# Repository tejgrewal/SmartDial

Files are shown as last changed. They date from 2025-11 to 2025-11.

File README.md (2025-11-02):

# SmartDial

This project is proff of concept, that used a Round Display, Dial, Haptics with power of ESP32-S3 as main controller.

Features
- Menu-driven launcher with games (Pong, Snake, Maze), Torch app and BLE-based Launcher.
- Uses Seeed_GFX / TFT_eSPI for display rendering.
- Haptics and BNO sensor support.
- Modular app interface via the Modulino knob.

CAD Folder- All the model files are in CAD folder

BOM Folder - Bill of material of the items required to make one SmartDial

Assembly & Fabrication Folder - Contain notes on important items. Please read carefully before commiting or start of project. 

Quick links to main code & modules
- [`src/main.cpp`](src/main.cpp)
- UI / menu: [`Menu::init`](lib/Menu/Menu.h)
- Torch app: [`Torch::initOnce`](lib/Apps/Torch.h)
- Pong: [`Pong::init`](lib/Games/Pong.h)
- Snake: [`Snake::init`](lib/Games/Snake.h)
- Maze: [`Maze::init`](lib/Games/Maze.h)
- Launcher (BLE GATT): [`Launcher::init`](lib/Launcher/Launcher.h)
- Lights (BLE UART-like): [`Lights::init`](lib/Lights/Lights.h)
- Storage: [`Storage::loadHighscores`](lib/Storage/Storage.h)
- BLE host helper: [`BLEHost::begin`](lib/BLE/BLEHost.h)
- Haptics: [`Haptics::begin`](lib/Haptics/Haptics.h)
- BNO sensor: [`Sensors::BNO::begin`](lib/Sensors/BNO.h)
- Seeed GFX setup selector: [lib/Seeed_GFX/User_Setup_Select.h](lib/Seeed_GFX/User_Setup_Select.h)

PlatformIO setup

1. Clone repository and open in VS Code + PlatformIO.
2. Platform/board used in this project:
   - CONFIGURATION: https://docs.platformio.org/page/boards/espressif32/seeed_xiao_esp32s3.html
   - PLATFORM: Espressif 32 (6.12.0)
   - BOARD: Seeed Studio XIAO ESP32S3
   - HARDWARE: ESP32S3 240MHz, 320KB RAM, 8MB Flash

3. The provided platformio.ini already includes the project environment:
   - [platformio.ini](platformio.ini)

4. Install libraries (PlatformIO will auto-install lib_deps from platformio.ini). To force-install locally, run:
```sh
pio lib install "arduino-libraries/Arduino_Modulino@^0.6.0" \
                "adafruit/Adafruit BNO08x@^1.2.5" \
                "adafruit/Adafruit DRV2605 Library@^1.2.4" \
                "adafruit/Adafruit GFX Library@^1.12.3" \
                "Seeed-Studio/Seeed_GFX@^2.0.3"
```

Build & flash
- Build (release mode in CI):
```sh
pio run -e seeed_xiao_esp32s3
```
- Build with verbose output:
```sh
pio run -e seeed_xiao_esp32s3 -v
```
- Upload (ensure board connected and correct upload method in platformio.ini):
```sh
pio run -e seeed_xiao_esp32s3 -t upload
```

Debugging
- Debug adapters supported (cmsis-dap, JLink, etc.) — see PlatformIO debug configuration in .vscode/launch.json.
- Toolchain & packages used by the environment (from CI):
  - framework-arduinoespressif32 @ 3.20017.241212+sha.dcc1105b
  - tool-esptoolpy @ 2.40900.250804
  - toolchain-riscv32-esp @ 8.4.0+2021r2-patch5
  - toolchain-xtensa-esp32s3 @ 8.4.0+2021r2-patch5

Notes & configuration hints
- Seeed_GFX is configured via the library User_Setups; if you change hardware or pinout edit:
  - [lib/Seeed_GFX/User_Setup_Select.h](lib/Seeed_GFX/User_Setup_Select.h)
  - See PlatformIO config examples: [lib/Seeed_GFX/docs/PlatformIO/Configuring options.txt](lib/Seeed_GFX/docs/PlatformIO/Configuring options.txt)
- The project relies on the Modulino knob API (Modulino library). The code uses `Modulino.begin()` and `knob.begin()` in [src/main.cpp](src/main.cpp).
- LDF: Library Dependency Finder found many compatible libraries for the selected environment. More on LDF: https://bit.ly/configure-pio-ldf

Troubleshooting
- If the TFT shows garbled output, confirm the active User_Setup file or set USER_SETUP_LOADED via PlatformIO build_flags per Seeed_GFX docs.
- Missing sensors or haptics are treated as non-fatal; core UI still runs.

License & contribution
- See repository LICENSE (if present) and individual library licenses (e.g. Seeed_GFX includes MIT/BSD components). Consult `lib/Seeed_GFX/license.txt` for details.

If you want, this README can be extended with a wiring diagram, per-board build targets, or a developer guide for adding new apps.

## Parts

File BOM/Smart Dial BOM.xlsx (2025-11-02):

Smart Dial BOM (Proff of Concept)
SR No. | Part Code | Description | QTY | Links | Notes
1 | 104030087 | Round Display for Seeed Studio XIAO | 1 | https://www.seeedstudio.com/Seeed-Studio-Round-Display-for-XIAO-p-5638.html | Required
2 | 113991114 | Seeed Studio XIAO ESP32-S3 | 1 | https://www.seeedstudio.com/XIAO-ESP32S3-p-5627.html | Required
3 | ABX00107 | Modulino® Knob | 1 | https://store-usa.arduino.cc/collections/modulino/products/modulino-knob | Required
4 | 4754 | Adafruit 9-DOF Orientation IMU Fusion Breakout - BNO085 | 1 | https://www.adafruit.com/product/4754 | Optional
5 | 2305 | Adafruit DRV2605L Haptic Motor Controller - STEMMA QT / Qwiic | 1 | https://www.adafruit.com/product/2305 | Optional
6 | NSC1040 | NSC1040 No.7 10440 Battery | 1 | https://www.aliexpress.com/p/tesla-landing/index.html?scenario=c_ppc_item_bridge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 | Required
7 | 99397A066 | 18-8 Stainless Steel, M1.91 Size, 5 mm Long | 8 | https://www.mcmaster.com/99397A066/ | Required
8 | 92095A454 | M2 x 0.40 mm Thread, 8mm Long | 3 | https://www.mcmaster.com/92095A454/ | Required
9 | 17260 | FLEXIBLE QWIIC CABLE - 50MM | 2 | https://www.digikey.ca/en/products/detail/sparkfun-electronics/17260/13629028 | Based on 4 and 5, Minimum 1 required. One comes with Modulino Board
10 | 450301014042-ND | SWITCH SLIDE SPDT 500MA 12V | 1 | https://www.digikey.ca/en/products/detail/w%C3%BCrth-elektronik/450301014042/5209104 | Required
11 | VLV221007E | VIBRATION LRA MOTOR 230HZ 8.0G | 1 | https://www.digikey.ca/en/products/detail/vybronics-inc/VLV221007E/21800154 | Optional

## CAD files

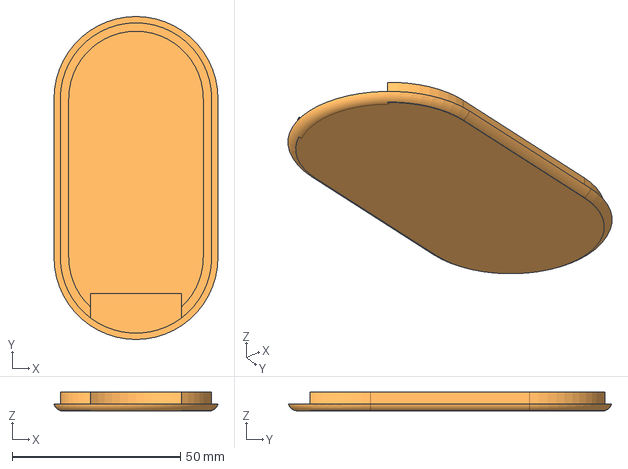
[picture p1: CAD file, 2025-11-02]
CAD/Main Enclosure - Bottom Cover.step
48.8 x 96.1 x 5.60 mm

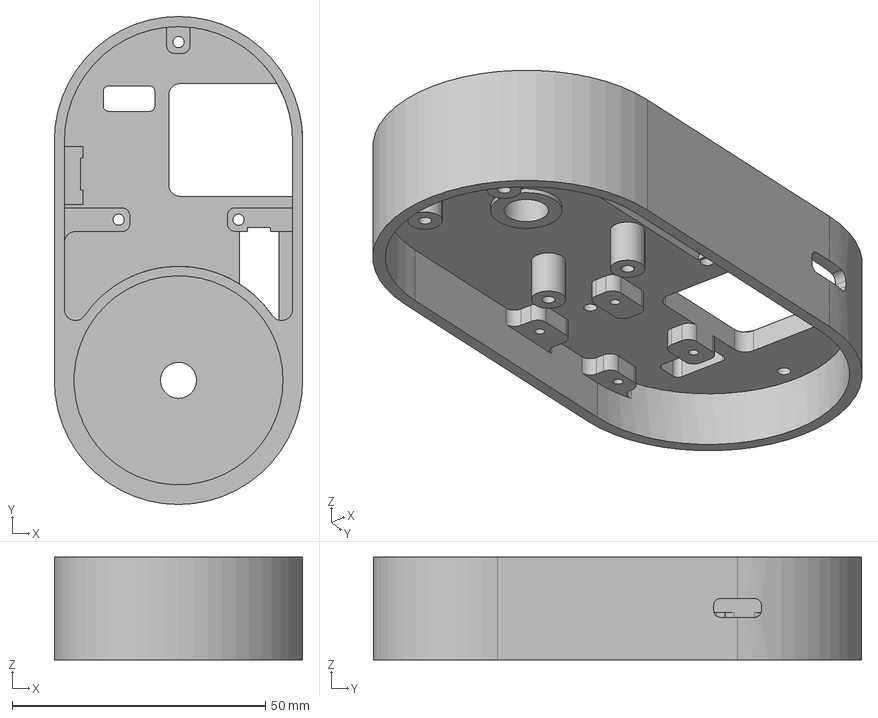
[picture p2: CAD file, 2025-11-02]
CAD/Main Enclosure - Case.step
49.0 x 96.3 x 20.3 mm

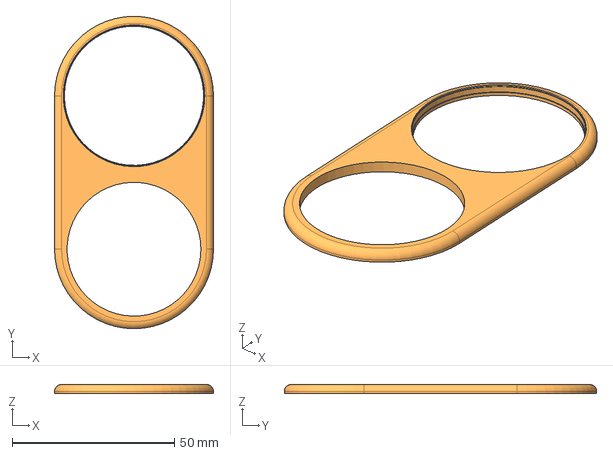
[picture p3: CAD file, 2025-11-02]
CAD/Main Enclosure - Top Cover.step
49.0 x 96.3 x 2.80 mm

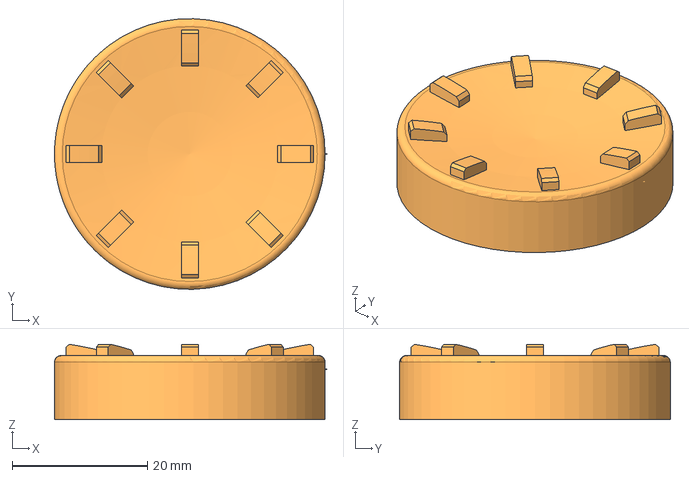
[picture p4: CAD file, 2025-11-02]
CAD/Dial.step
40.2 x 40.0 x 11.1 mm

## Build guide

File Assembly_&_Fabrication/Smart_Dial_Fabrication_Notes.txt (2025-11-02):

Fabrication Notes
1. All the CAD parts are 3d printable.
2. Top Cover and Bottom Cover - Printed using PETG Transparent (check https://www.instagram.com/reel/DPusf-8j6Yj/?utm_source=ig_web_copy_link&igsh=MzRlODBiNWFlZA== )
3. Case or the main holding part - Printed using PLA Black ( The part was split from center for better best accuracy and joined using T7000 Glue - check  https://www.instagram.com/reel/DPpqfsNkRqw/?utm_source=ig_web_copy_link&igsh=MzRlODBiNWFlZA==)
4. Dial - Printed using PLA RED and BLUE

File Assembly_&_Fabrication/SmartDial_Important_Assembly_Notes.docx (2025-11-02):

Important Assembly Notes

This project, being proof of concept, has two limitations that are easy to solve and involves manual soldering.

1. Xiao Round Display does not provide connector for external switch

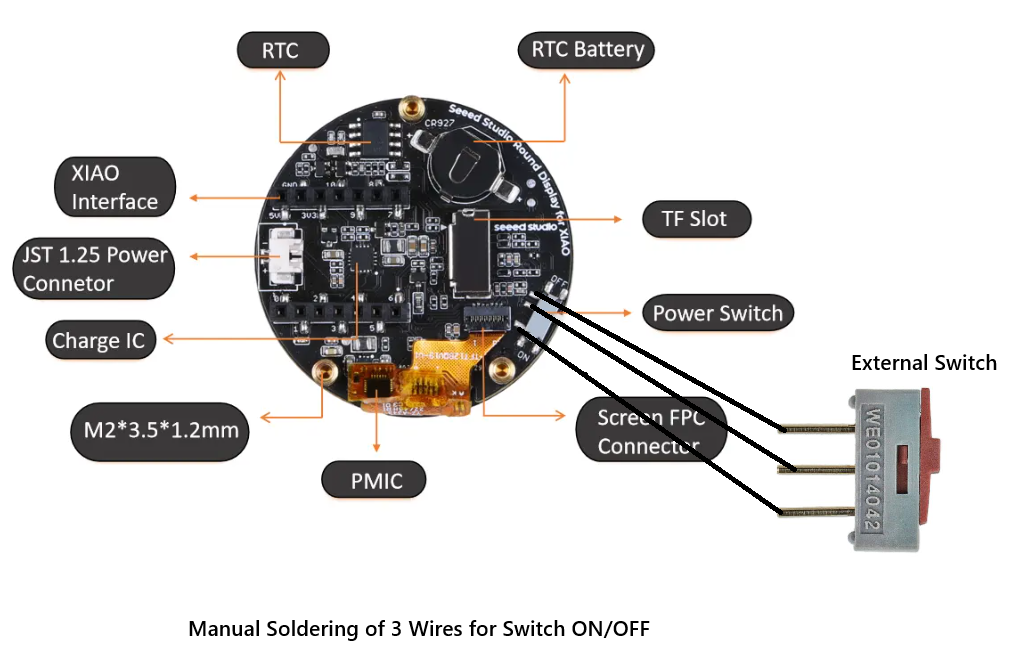
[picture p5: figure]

2. Xiao Board also does not provide connector to I2C line

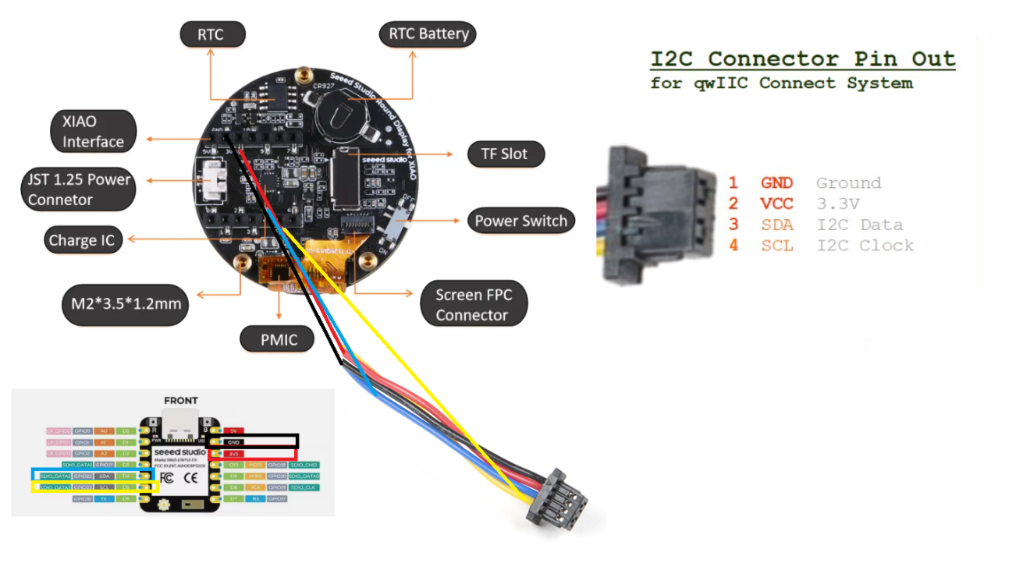
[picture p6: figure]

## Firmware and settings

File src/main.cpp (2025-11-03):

#include <Arduino.h>
#include <SPI.h>
#include <TFT_eSPI.h>
#include <Modulino.h>

// Core modules
#include "Theme.h"
#include "Haptics.h"
#include "Storage.h"
#include "Menu.h"

// Games & apps
#include "Pong.h"
#include "Snake.h"
#include "Maze.h"
#include "Torch.h"
#include "Launcher.h"     // BLE GATT launcher
#include "Highscores.h"
#include "About.h"
#include "BNO.h"
#include "BLEHost.h"
#include "Lights.h"       // BLE UART-like server (NimBLE)
#include "measure.h"      // <-- NEW: center-out measurement tool
#include "Aim.h"          // <-- AIM

TFT_eSPI tft;
TFT_eSprite sprite(&tft);
ModulinoKnob knob;

static AppState appState = AppState::STATE_MENU;
static uint32_t lastUs = 0;

// ---- App glue helpers ----
static void goMenu()        { appState = AppState::STATE_MENU; Menu::startPop(); }
static void startPong()     { appState = AppState::STATE_PONG;     Pong::reset(); }
static void startSnake()    { appState = AppState::STATE_SNAKE;    Snake::reset(); }
static void startMaze()     { appState = AppState::STATE_MAZE;     Maze::reset(); }
static void startTorch()    { appState = AppState::STATE_TORCH;    Torch::init(); }
static void showHighscores(){ appState = AppState::STATE_HISCORES; Storage::loadHighscores(); }
static void showAbout()     { appState = AppState::STATE_ABOUT; }
static void startLauncher() { appState = AppState::STATE_LAUNCHER; Launcher::init(sprite, knob); }
static void startLights()   { appState = AppState::STATE_LIGHTS;   Lights::init(sprite, knob); }
static void startMeasure()  { appState = AppState::STATE_MEASURE;  Measure::enter(knob); } // <-- NEW
static void startAim()      { appState = AppState::STATE_AIM; }                          // <-- AIM

void setup() {
  Serial.begin(115200);

  Modulino.begin();
  knob.begin();

  tft.init();
  tft.setRotation(0);
  tft.fillScreen(TFT_BLACK);

  sprite.setSwapBytes(true);
  sprite.createSprite(SCREEN_WIDTH, SCREEN_HEIGHT);

  // Init subsystems
  Haptics::begin();
  Sensors::BNO::begin();        // non-fatal if missing
  Storage::loadHighscores();

  // BLE UART-like service (desktop helper connects to this)
  BLEHost::begin("QubeLauncher");

  // Init pages/games
  Menu::init(sprite, knob);
  Pong::init(sprite, knob);
  Snake::init(sprite, knob);
  Maze::init(sprite, knob);
  Torch::initOnce(sprite);
  Highscores::init(sprite, knob);
  About::init(sprite, knob);
  Measure::init(sprite, knob);            // <-- NEW (once at boot)
  Aim::init(sprite, knob);                // <-- AIM (once at boot)
  // Optionally calibrate your screen width in mm:
  // Measure::setScreenWidthMM(32.4f);

  lastUs = micros();
  goMenu();
}

void loop() {
  // ---- Press edge (shared) ----
  static bool pressed = false;
  if (knob.isPressed()) {
    if (!pressed) pressed = true;
  } else if (pressed) {
    pressed = false;
    Haptics::press();

    if (appState == AppState::STATE_MENU) {
      switch (Menu::currentId()) {
        case MenuId::M_HOME:      break; // reserved
        case MenuId::M_BULB:      startLights();   break;
        case MenuId::M_LAUNCHER:  startLauncher(); break;
        case MenuId::M_TORCH:     startTorch();    break;
        case MenuId::M_MEASURE:   startMeasure();  break;   // <-- NEW
        case MenuId::M_PONG:      startPong();     break;
        case MenuId::M_SNAKE:     startSnake();    break;
        case MenuId::M_MAZE:      startMaze();     break;
        case MenuId::M_AIM:       startAim();      break;   // <-- AIM
        case MenuId::M_HISCORES:  showHighscores();break;
        case MenuId::M_ABOUT:     showAbout();     break;
      }

    } else if (appState == AppState::STATE_TORCH) {
      Haptics::back();
      goMenu();

    } else if (appState == AppState::STATE_MEASURE) {   // <-- NEW: exit Measure on press
      Haptics::back();
      goMenu();

    } else if (appState == AppState::STATE_PONG) {
      Pong::onPress(goMenu);

    } else if (appState == AppState::STATE_SNAKE) {
      Snake::onPress(goMenu);

    } else if (appState == AppState::STATE_MAZE) {
      Maze::onPress(goMenu);

    } else if (appState == AppState::STATE_AIM) {       // <-- AIM
      Aim::onPress(goMenu);

    } else if (appState == AppState::STATE_HISCORES) {
      Highscores::onPress(goMenu);

    } else if (appState == AppState::STATE_ABOUT) {
      // deliver press to About page (will call goMenu() or set its exit flag)
      About::onPress(goMenu);

    } else if (appState == AppState::STATE_LIGHTS) {
      // IMPORTANT: do nothing here — Lights handles press internally.
      // (No goMenu(); keep the app active.)

    } else if (appState == AppState::STATE_LAUNCHER) {
      // Same idea: let Launcher handle its own presses / wantsExit().
      // (No goMenu();)

    } else {
      // For any truly unknown state, you can still fall back to menu:
      // goMenu();
    }
  }

  // ---- Frame pacing (~30 FPS) ----
  const uint32_t nowUs = micros();
  if (nowUs - lastUs < FRAME_US) return;
  const float dt = float(nowUs - lastUs) / 1e6f;
  lastUs = nowUs;

  // ---- State machine ----
  switch (appState) {
    case AppState::STATE_MENU:
      Menu::tickAndDraw(sprite, knob);
      break;

    case AppState::STATE_TORCH:
      Torch::step();
      Torch::render(sprite);
      break;

    case AppState::STATE_HISCORES:
      Highscores::tickAndDraw(sprite, knob);
      break;

    case AppState::STATE_ABOUT:
      About::draw(sprite);
      break;

    case AppState::STATE_PONG:
      Pong::tick(dt);
      Pong::draw(sprite);
      break;

    case AppState::STATE_SNAKE:
      Snake::tick();
      Snake::draw(sprite);
      break;

    case AppState::STATE_MAZE:
      Maze::tick(dt);
      Maze::draw(sprite);
      break;

    // ---- NEW: BLE Launcher page ----
    case AppState::STATE_LAUNCHER:
      Launcher::tickAndDraw(sprite, knob);
      if (Launcher::wantsExit()) {
        Haptics::back();
        goMenu();
      }
      break;

    case AppState::STATE_LIGHTS:
      Lights::tickAndDraw(sprite, knob);
      if (Lights::wantsExit()) { Haptics::back(); goMenu(); }
      break;

    case AppState::STATE_MEASURE:                // <-- NEW
      Measure::tickAndDraw(sprite, knob);
      sprite.pushSprite(0,0);
      break;

    case AppState::STATE_AIM:                    // <-- AIM
      Aim::tick(dt);
      Aim::draw(sprite);
      break;
  }
}

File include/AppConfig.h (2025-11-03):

#ifndef QUBE_APPCONFIG_H
#define QUBE_APPCONFIG_H

#include <TFT_eSPI.h>

// Display
constexpr int SCREEN_WIDTH  = 240;
constexpr int SCREEN_HEIGHT = 240;
constexpr int CX = SCREEN_WIDTH/2;
constexpr int CY = SCREEN_HEIGHT/2;

// Timing
constexpr uint32_t FRAME_US = 33000; // ~30 FPS

// App states
enum class AppState {
  STATE_MENU,
  STATE_PONG,
  STATE_SNAKE,
  STATE_MAZE,
  STATE_TORCH,
  STATE_LAUNCHER,
  STATE_HISCORES,
  STATE_ABOUT,
  STATE_LIGHTS,
  STATE_MEASURE,
  STATE_AIM    
};

#endif // QUBE_APPCONFIG_H

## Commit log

2025-10-30 Bug Removal, Game Push Menu, High Score Page
    [main.cpp]
2025-11-02 Fab & Assembly Files
